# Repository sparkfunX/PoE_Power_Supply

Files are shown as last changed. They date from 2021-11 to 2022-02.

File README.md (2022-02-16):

SparkFun PoE to USB Power Supply
===========================================================

SparkFun PoE to USB Power Supply (https://www.sparkfun.com/products/18709)

[*SparkFun PoE to USB Power Supply (SPX-18709)*](https://www.sparkfun.com/products/18709)

It can be difficult to get a wall-wart where you need it. The promise of PoE (power over ethernet) is great, but what if your device doesn't use ethernet? Perhaps you could mess with power injectors, but what if you've already got PoE available on your network? The PoE to USB Power Supply is like a USB wall wart for PoE. Get a PoE hub, run ethernet wherever you need it, plug the PoE to USB Power Supply in and you'll have 5V at 1A via a USB A connector.

The onboard PoE module supports 36V to 57V DC input and provides up to 1.8A (9W) output. While the module claims 1.8A, we've pushed it to 1.5A before the module hit 75C and the output began to sag below 4.5V. The PoE to USB Power Supply has 1.5KV isolation, thermal cut off, and short circuit protection. The PoE module requires a 100mA load at all times so the PoE Power Supply includes a 50 Ohm resistor to constantly load the module with 100mA. There's a cuttable jumper to remove this load if needed. At a 1A load we measured a low 20mVPP ripple at 200kHz.

Who doesn't need 3.3V as well? In addition to the 5V provided via USB we've added a 3.3V 600mA regulator as well that can be connected via PTH solder connections. This is handy for systems running directly at 3.3V.

Repository Contents
-------------------

* **/Hardware** - Eagle files

License Information
-------------------

This product is _**open source**_! 

Various bits of the code have different licenses applied. Anything SparkFun wrote is beerware; if you see me (or any other SparkFun employee) at the local, and you've found our code helpful, please buy us a round!

Please use, reuse, and modify these files as you see fit. Please maintain attribution to SparkFun Electronics and release anything derivative under the same license.

Distributed as-is; no warranty is given.

- Your friends at SparkFun.

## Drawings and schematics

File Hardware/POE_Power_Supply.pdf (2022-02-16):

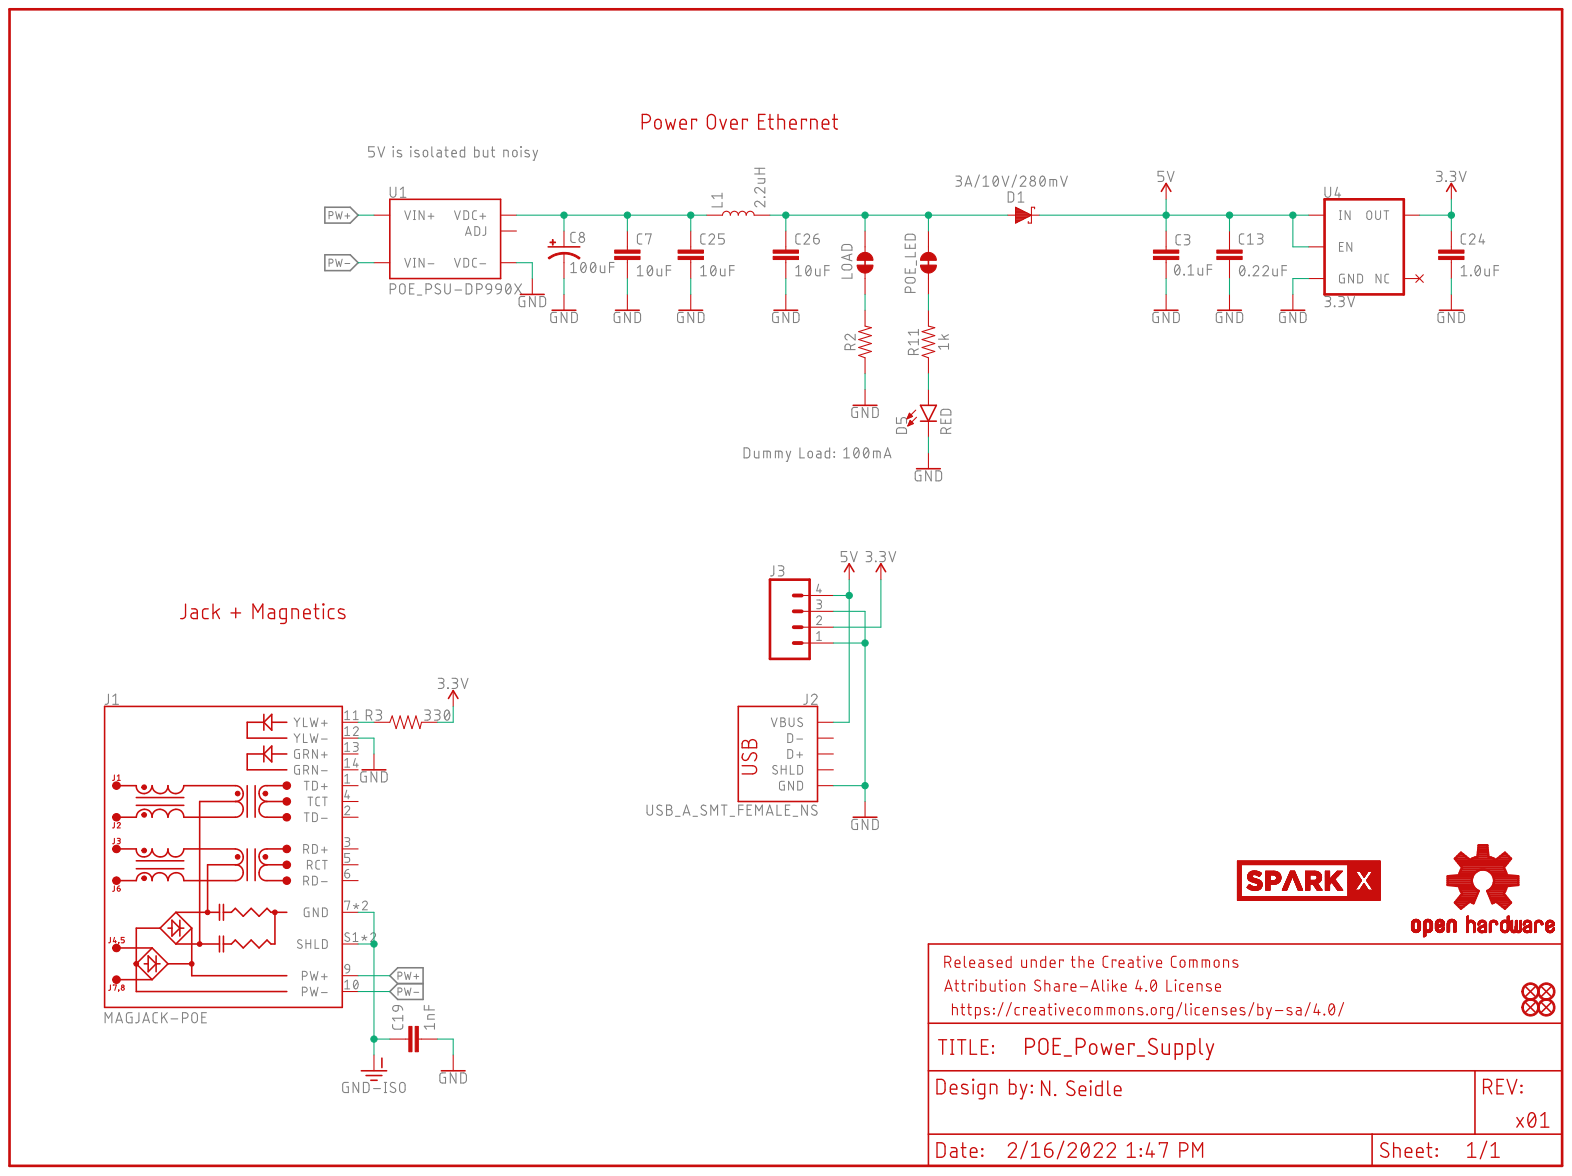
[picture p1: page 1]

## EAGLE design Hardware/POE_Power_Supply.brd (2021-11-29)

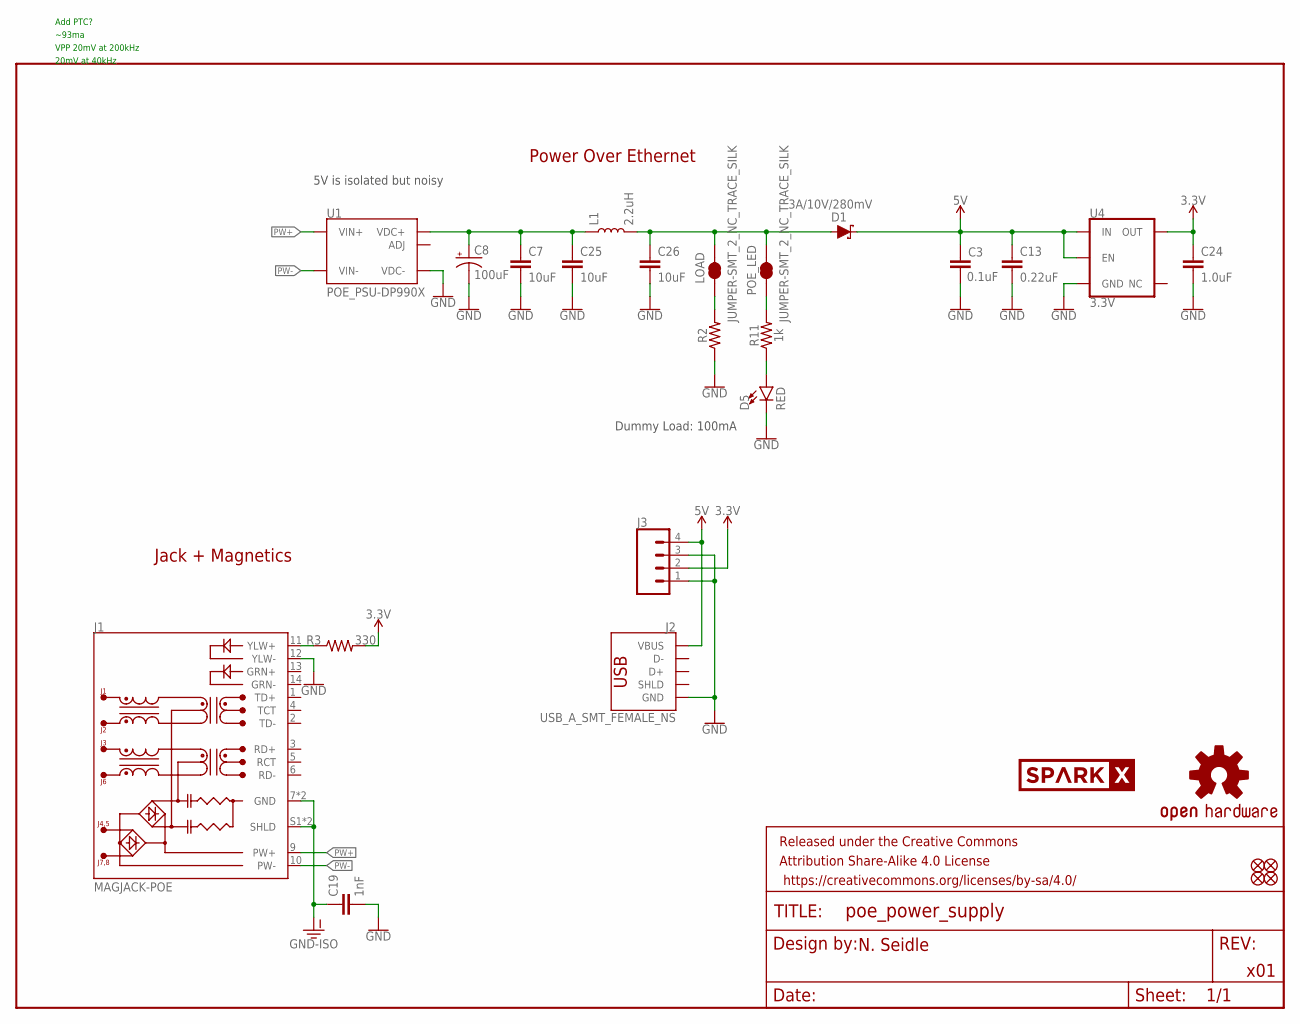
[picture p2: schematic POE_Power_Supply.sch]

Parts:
C3: 0.1uF; 0603
C7, C25, C26: 10uF; 0805
C8: 100uF; PANASONIC_D
C13: 0.22uF; 0603
C19: 1nF; 1206
C24: 1.0uF; 0603
D1: 3A/10V/280mV; SOD-323
D5: RED; LED-0603
FD1, FD2, FD3, FD4: FIDUCIALUFIDUCIAL; FIDUCIAL-MICRO
FRAME1: FRAME-LETTER; CREATIVE_COMMONS
J1: MAGJACK-POE; MAGJACK-SYM_LED
J2: USB_A_SMT_FEMALE_NS; USB-A-S-NOSILK-FEMALE
J3: CONN_041X04_NO_SILK; 1X04_NO_SILK
L1: 2.2uH; 0805-WIDE
LOAD: JUMPER-SMT_2_NC_TRACE_SILK; SMT-JUMPER_2_NC_TRACE_SILK
LOGO3: OSHW-LOGOMINI; OSHW-LOGO-MINI
POE_LED: JUMPER-SMT_2_NC_TRACE_SILK; SMT-JUMPER_2_NC_TRACE_SILK
R2: 49.9OHM-1206-1/2W-1%; 1206
R3: 330; 0603
R11: 1k; 0603
U1: POE_PSU-DP990X; DP990X
U4: 3.3V; SOT23-5
U$7: SPARKX-LOGO4; SPARKX-MEDIUM

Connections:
3.3V: C24.1, J3.2, R3.2, U4.5 (OUT)
5V: C3.1, C13.1, D1.C, J2.VBUS, J3.4, U4.1 (IN), U4.3 (EN)
5V_FILTER: C26.1, D1.A, L1.2, LOAD.2, POE_LED.2
5V_RAW: C7.1, C8.+, C25.1, L1.1, U1.1 (VDC+), U1.2 (VDC+)
GND: C3.2, C7.2, C8.-, C13.2, C19.2, C24.2, C25.2, C26.2, D5.C, J1.12 (YLW-), J2.GND, J3.1, J3.3, R2.1, U1.3 (VDC-), U4.2 (GND)
GND-ISO: C19.1, J1.7 (GND), J1.8 (GND), J1.S1 (SHLD), J1.S2 (SHLD)
unnamed: D5.A, R11.1
unnamed: POE_LED.1, R11.2
unnamed: LOAD.1, R2.2
unnamed: J1.11 (YLW+), R3.1
PW+: J1.9 (PW+), U1.5 (VIN+), U1.6 (VIN+)
PW-: J1.10 (PW-), U1.7 (VIN-), U1.8 (VIN-)

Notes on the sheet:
5V is isolated but noisy
x01
Jack + Magnetics
N. Seidle
Power Over Ethernet
Dummy Load: 100mA
Add PTC?
~93ma
VPP 20mV at 200kHz
20mV at 40kHz

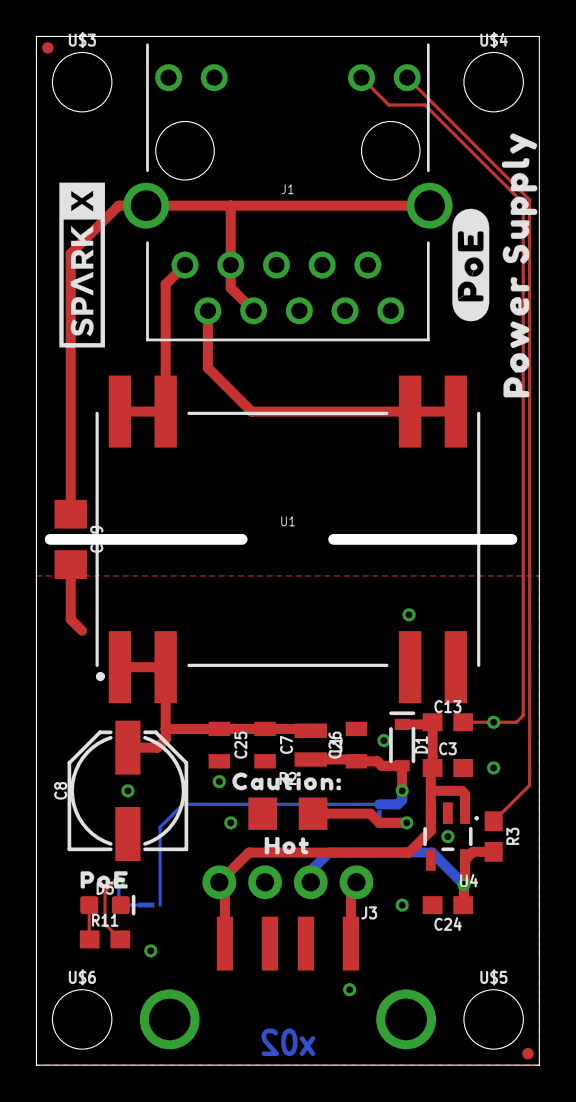
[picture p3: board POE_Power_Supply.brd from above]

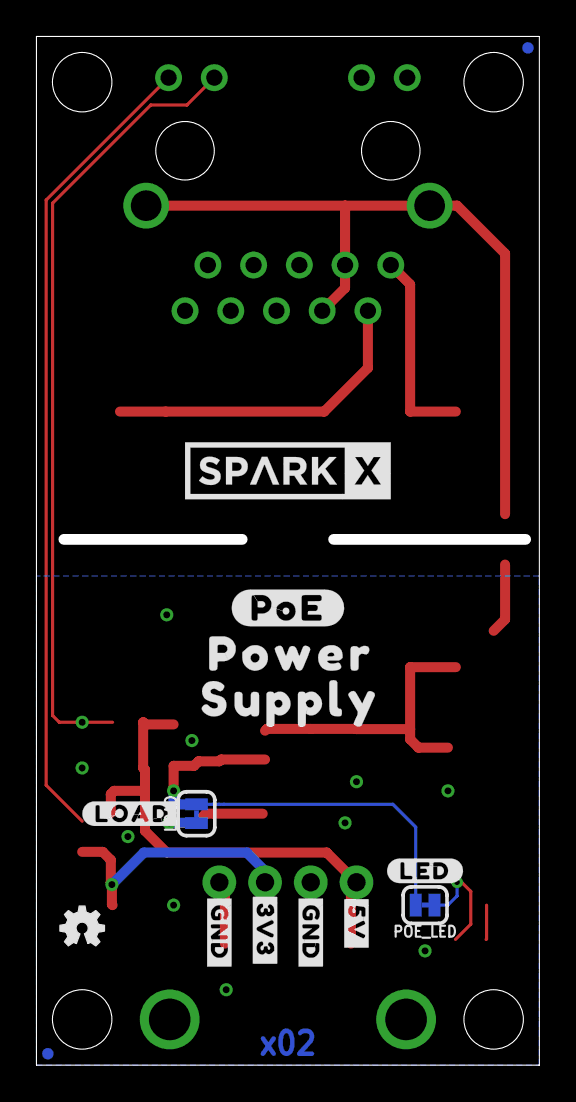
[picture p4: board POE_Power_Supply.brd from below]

Board: 2 copper layers, 27.9 x 57.1 mm, 48 parts (15 on the bottom side), 12 nets.

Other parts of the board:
U$1, U$18: #POE#0
U$3, U$4, U$5, U$6: STAND-OFF
U$8: #LED#0
U$9: #LOAD#0
U$10: #3V3#0
U$11: #5V#2
U$12, U$13: #GND#1
U$14: CAUTION#0
U$15: HOT1
U$16: POE0
U$17: POWER_0
U$19: SPARKX-LOGO4; SPARKX-LARGE
U$20: POWER0
U$21: SUPPLY1
U$22: SUPPLY_1

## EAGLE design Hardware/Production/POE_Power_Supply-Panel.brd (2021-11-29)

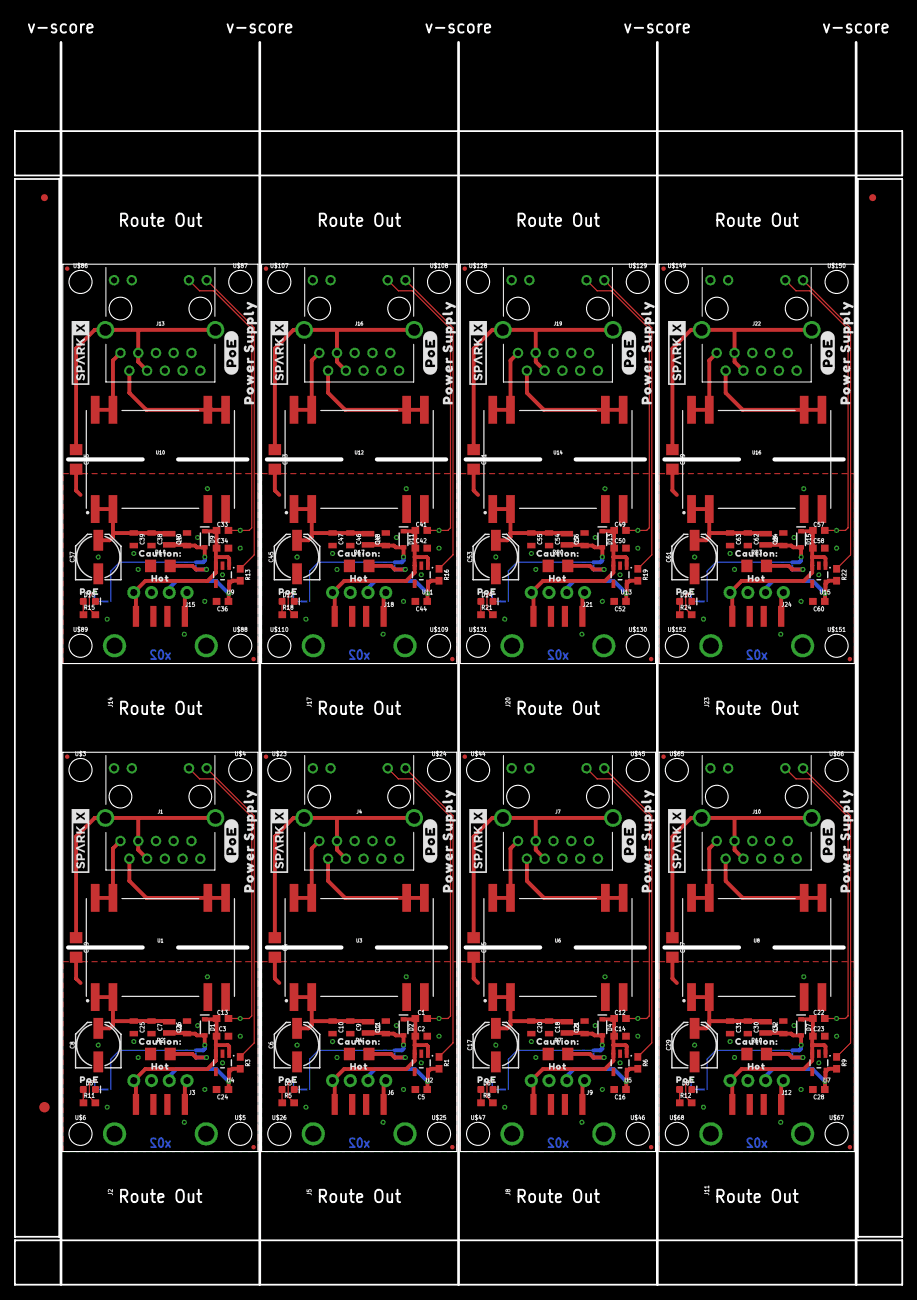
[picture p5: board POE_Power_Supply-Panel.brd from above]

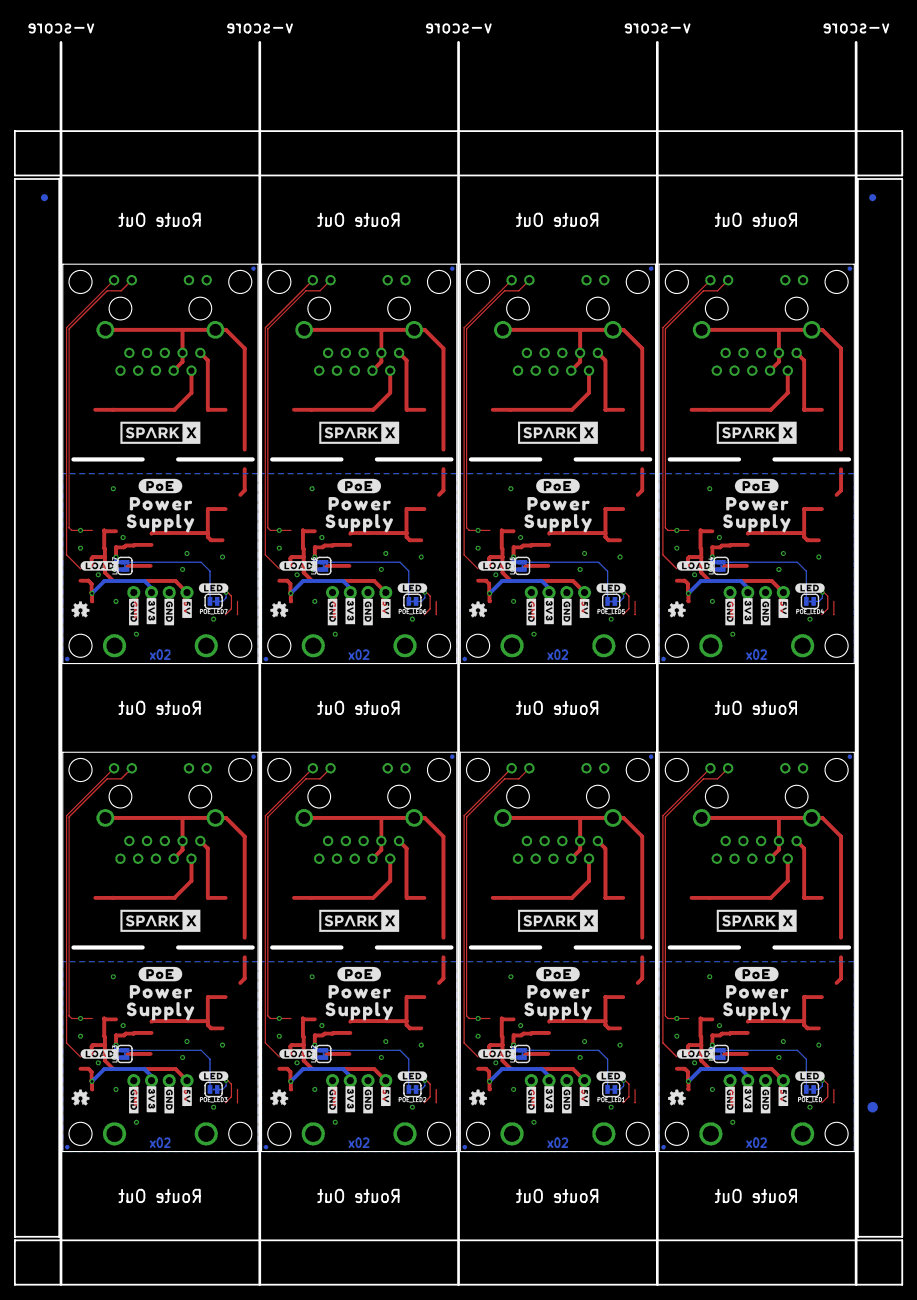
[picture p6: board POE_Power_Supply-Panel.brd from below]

Board: 2 copper layers, 127.0 x 177.8 mm, 382 parts (123 on the bottom side), 96 nets.

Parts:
C1, C12, C13, C22, C33, C41, C49, C57: 0.22uF; 0603
C2, C3, C14, C23, C34, C42, C50, C58: 0.1uF; 0603
C4, C15, C19, C27, C35, C43, C51, C59: 1nF; 1206
C5, C16, C24, C28, C36, C44, C52, C60: 1.0uF; 0603
C6, C8, C17, C29, C37, C45, C53, C61: 100uF; PANASONIC_D
C7, C9, C10, C11, C18, C20, C21, C25, C26, C30, C31, C32, C38, C39, C40, C46, C47, C48, C54, C55, C56, C62, C63, C64: 10uF; 0805
D1, D2, D4, D7, D9, D11, D13, D15: 3A/10V/280mV; SOD-323
D3, D5, D6, D8, D10, D12, D14, D16: RED; LED-0603
E$1, E$2, E$3, E$4: FIDUCIAL-1X2
E$5, E$6: FIDUCIAL-1.5X3
FD1, FD2, FD3, FD4, FD5, FD6, FD7, FD8, FD9, FD10, FD11, FD12, FD13, FD14, FD15, FD16, FD17, FD18, FD19, FD20, FD21, FD22, FD23, FD24, FD25, FD26, FD27, FD28, FD29, FD30, FD31, FD32: FIDUCIALUFIDUCIAL; FIDUCIAL-MICRO
J1, J4, J7, J10, J13, J16, J19, J22: MAGJACK-POE; MAGJACK-SYM_LED
J2, J5, J8, J11, J14, J17, J20, J23: USB_A_SMT_FEMALE_NS; USB-A-S-NOSILK-FEMALE
J3, J6, J9, J12, J15, J18, J21, J24: 1X04_NO_SILK
L1, L2, L3, L4, L5, L6, L7, L8: 2.2uH; 0805-WIDE
LOAD, LOAD1, LOAD2, LOAD3, LOAD4, LOAD5, LOAD6, LOAD7: JUMPER-SMT_2_NC_TRACE_SILK; SMT-JUMPER_2_NC_TRACE_SILK
LOGO1, LOGO2, LOGO3, LOGO4, LOGO5, LOGO6, LOGO7, LOGO8: OSHW-LOGOMINI; OSHW-LOGO-MINI
POE_LED, POE_LED1, POE_LED2, POE_LED3, POE_LED4, POE_LED5, POE_LED6, POE_LED7: JUMPER-SMT_2_NC_TRACE_SILK; SMT-JUMPER_2_NC_TRACE_SILK
R1, R3, R6, R9, R13, R16, R19, R22: 330; 0603
R2, R4, R7, R10, R14, R17, R20, R23: 49.9OHM-1206-1/2W-1%; 1206
R5, R8, R11, R12, R15, R18, R21, R24: 1k; 0603
U1, U3, U6, U8, U10, U12, U14, U16: POE_PSU-DP990X; DP990X
U2, U4, U5, U7, U9, U11, U13, U15: 3.3V; SOT23-5
U$1, U$2, U$18, U$42, U$43, U$63, U$64, U$84, U$85, U$105, U$106, U$126, U$127, U$147, U$148, U$168: #POE#0
U$3, U$4, U$5, U$6, U$23, U$24, U$25, U$26, U$44, U$45, U$46, U$47, U$65, U$66, U$67, U$68, U$86, U$87, U$88, U$89, U$107, U$108, U$109, U$110, U$128, U$129, U$130, U$131, U$149, U$150, U$151, U$152: STAND-OFF
U$7, U$36, U$57, U$78, U$99, U$120, U$141, U$162: SPARKX-LOGO4; SPARKX-MEDIUM
U$8, U$27, U$48, U$69, U$90, U$111, U$132, U$153: #LED#0
U$9, U$28, U$49, U$70, U$91, U$112, U$133, U$154: #LOAD#0
U$10, U$29, U$50, U$71, U$92, U$113, U$134, U$155: #3V3#0
U$11, U$30, U$51, U$72, U$93, U$114, U$135, U$156: #5V#2
U$12, U$13, U$31, U$32, U$52, U$53, U$73, U$74, U$94, U$95, U$115, U$116, U$136, U$137, U$157, U$158: #GND#1
U$14, U$33, U$54, U$75, U$96, U$117, U$138, U$159: CAUTION#0
U$15, U$34, U$55, U$76, U$97, U$118, U$139, U$160: HOT1
U$16, U$35, U$56, U$77, U$98, U$119, U$140, U$161: POE0
U$17, U$40, U$61, U$82, U$103, U$124, U$145, U$166: POWER_0
U$19, U$37, U$58, U$79, U$100, U$121, U$142, U$163: SPARKX-LOGO4; SPARKX-LARGE
U$20, U$38, U$59, U$80, U$101, U$122, U$143, U$164: POWER0
U$21, U$39, U$60, U$81, U$102, U$123, U$144, U$165: SUPPLY1
U$22, U$41, U$62, U$83, U$104, U$125, U$146, U$167: SUPPLY_1

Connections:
3.3V: C24.1, J3.2, R3.2, U4.5
3.3V1: C5.1, J6.2, R1.2, U2.5
3.3V2: C16.1, J9.2, R6.2, U5.5
3.3V3: C28.1, J12.2, R9.2, U7.5
3.3V4: C36.1, J15.2, R13.2, U9.5
3.3V5: C44.1, J18.2, R16.2, U11.5
3.3V6: C52.1, J21.2, R19.2, U13.5
3.3V7: C60.1, J24.2, R22.2, U15.5
5V: C3.1, C13.1, D1.C, J2.VBUS, J3.4, U4.1, U4.3
5V1: C1.1, C2.1, D2.C, J5.VBUS, J6.4, U2.1, U2.3
5V2: C12.1, C14.1, D4.C, J8.VBUS, J9.4, U5.1, U5.3
5V3: C22.1, C23.1, D7.C, J11.VBUS, J12.4, U7.1, U7.3
5V4: C33.1, C34.1, D9.C, J14.VBUS, J15.4, U9.1, U9.3
5V5: C41.1, C42.1, D11.C, J17.VBUS, J18.4, U11.1, U11.3
5V6: C49.1, C50.1, D13.C, J20.VBUS, J21.4, U13.1, U13.3
5V7: C57.1, C58.1, D15.C, J23.VBUS, J24.4, U15.1, U15.3
5V_FILTER: C26.1, D1.A, L1.2, LOAD.2, POE_LED.2
5V_FILTER1: C11.1, D2.A, L2.2, LOAD1.2, POE_LED1.2
5V_FILTER2: C21.1, D4.A, L3.2, LOAD2.2, POE_LED2.2
5V_FILTER3: C32.1, D7.A, L4.2, LOAD3.2, POE_LED3.2
5V_FILTER4: C40.1, D9.A, L5.2, LOAD4.2, POE_LED4.2
5V_FILTER5: C48.1, D11.A, L6.2, LOAD5.2, POE_LED5.2
5V_FILTER6: C56.1, D13.A, L7.2, LOAD6.2, POE_LED6.2
5V_FILTER7: C64.1, D15.A, L8.2, LOAD7.2, POE_LED7.2
5V_RAW: C7.1, C8.+, C25.1, L1.1, U1.1, U1.2
5V_RAW1: C6.+, C9.1, C10.1, L2.1, U3.1, U3.2
5V_RAW2: C17.+, C18.1, C20.1, L3.1, U6.1, U6.2
5V_RAW3: C29.+, C30.1, C31.1, L4.1, U8.1, U8.2
5V_RAW4: C37.+, C38.1, C39.1, L5.1, U10.1, U10.2
5V_RAW5: C45.+, C46.1, C47.1, L6.1, U12.1, U12.2
5V_RAW6: C53.+, C54.1, C55.1, L7.1, U14.1, U14.2
5V_RAW7: C61.+, C62.1, C63.1, L8.1, U16.1, U16.2
GND: C3.2, C7.2, C8.-, C13.2, C19.2, C24.2, C25.2, C26.2, D5.C, J1.12, J2.GND, J3.1, J3.3, R2.1, U1.3, U4.2
GND1: C1.2, C2.2, C4.2, C5.2, C6.-, C9.2, C10.2, C11.2, D3.C, J4.12, J5.GND, J6.1, J6.3, R4.1, U2.2, U3.3
GND2: C12.2, C14.2, C15.2, C16.2, C17.-, C18.2, C20.2, C21.2, D6.C, J7.12, J8.GND, J9.1, J9.3, R7.1, U5.2, U6.3
GND3: C22.2, C23.2, C27.2, C28.2, C29.-, C30.2, C31.2, C32.2, D8.C, J10.12, J11.GND, J12.1, J12.3, R10.1, U7.2, U8.3
GND4: C33.2, C34.2, C35.2, C36.2, C37.-, C38.2, C39.2, C40.2, D10.C, J13.12, J14.GND, J15.1, J15.3, R14.1, U9.2, U10.3
GND5: C41.2, C42.2, C43.2, C44.2, C45.-, C46.2, C47.2, C48.2, D12.C, J16.12, J17.GND, J18.1, J18.3, R17.1, U11.2, U12.3
GND6: C49.2, C50.2, C51.2, C52.2, C53.-, C54.2, C55.2, C56.2, D14.C, J19.12, J20.GND, J21.1, J21.3, R20.1, U13.2, U14.3
GND7: C57.2, C58.2, C59.2, C60.2, C61.-, C62.2, C63.2, C64.2, D16.C, J22.12, J23.GND, J24.1, J24.3, R23.1, U15.2, U16.3
GND-ISO: C19.1, J1.7, J1.8, J1.S1, J1.S2
GND-ISO1: C4.1, J4.7, J4.8, J4.S1, J4.S2
GND-ISO2: C15.1, J7.7, J7.8, J7.S1, J7.S2
GND-ISO3: C27.1, J10.7, J10.8, J10.S1, J10.S2
GND-ISO4: C35.1, J13.7, J13.8, J13.S1, J13.S2
GND-ISO5: C43.1, J16.7, J16.8, J16.S1, J16.S2
GND-ISO6: C51.1, J19.7, J19.8, J19.S1, J19.S2
GND-ISO7: C59.1, J22.7, J22.8, J22.S1, J22.S2
unnamed: J4.11, R1.1
unnamed: LOAD1.1, R4.2
unnamed: POE_LED1.1, R5.2
unnamed: D3.A, R5.1
unnamed: D5.A, R11.1
unnamed: POE_LED.1, R11.2
unnamed: J7.11, R6.1
unnamed: LOAD2.1, R7.2
unnamed: LOAD.1, R2.2
unnamed: J1.11, R3.1
unnamed: POE_LED2.1, R8.2
unnamed: D6.A, R8.1
unnamed: J10.11, R9.1
unnamed: LOAD3.1, R10.2
unnamed: POE_LED3.1, R12.2
unnamed: D8.A, R12.1
unnamed: J13.11, R13.1
unnamed: LOAD4.1, R14.2
unnamed: POE_LED4.1, R15.2
unnamed: D10.A, R15.1
unnamed: J16.11, R16.1
unnamed: LOAD5.1, R17.2
unnamed: POE_LED5.1, R18.2
unnamed: D12.A, R18.1
unnamed: J19.11, R19.1
unnamed: LOAD6.1, R20.2
unnamed: POE_LED6.1, R21.2
unnamed: D14.A, R21.1
unnamed: J22.11, R22.1
unnamed: LOAD7.1, R23.2
unnamed: POE_LED7.1, R24.2
unnamed: D16.A, R24.1
PW+: J1.9, U1.5, U1.6
PW+1: J4.9, U3.5, U3.6
PW+2: J7.9, U6.5, U6.6
PW+3: J10.9, U8.5, U8.6
PW+4: J13.9, U10.5, U10.6
PW+5: J16.9, U12.5, U12.6
PW+6: J19.9, U14.5, U14.6
PW+7: J22.9, U16.5, U16.6
PW-: J1.10, U1.7, U1.8
PW-1: J4.10, U3.7, U3.8
PW-2: J7.10, U6.7, U6.8
PW-3: J10.10, U8.7, U8.8
PW-4: J13.10, U10.7, U10.8
PW-5: J16.10, U12.7, U12.8
PW-6: J19.10, U14.7, U14.8
PW-7: J22.10, U16.7, U16.8

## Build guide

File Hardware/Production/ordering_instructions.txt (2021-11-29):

panel size, 128x166mm
PCB thickness, 1.6mm
number of layers, 2
soldermask color, Black
silkscreen color, White
oz copper, 1oz
finish, HASL lead free
stencils, none
pcs per panel, 8
min trace width, 0.1778mm / 0.0070in
min drill size, 0.3048mm / 0.0120in

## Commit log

2021-10-27 Add silk labels. Remove backup files. Add ignore.
    [POE_Power_Supply.brd, POE_Power_Supply.sch]
2021-10-27 Add dims.
    [POE_Power_Supply.brd]
2021-11-29 Update x02. Fix FP for load resistor.
    [POE_Power_Supply-Panel.brd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]
2022-02-16 Add schematic
    [POE_Power_Supply.sch]

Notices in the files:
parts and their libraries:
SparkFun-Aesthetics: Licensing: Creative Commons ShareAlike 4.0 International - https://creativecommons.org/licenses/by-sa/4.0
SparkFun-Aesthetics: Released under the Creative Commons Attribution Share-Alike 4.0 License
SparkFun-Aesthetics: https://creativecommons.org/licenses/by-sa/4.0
